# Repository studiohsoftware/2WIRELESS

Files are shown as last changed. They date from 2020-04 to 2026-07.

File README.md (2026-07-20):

# 2WIRELESS
# Wireless Preset Manager

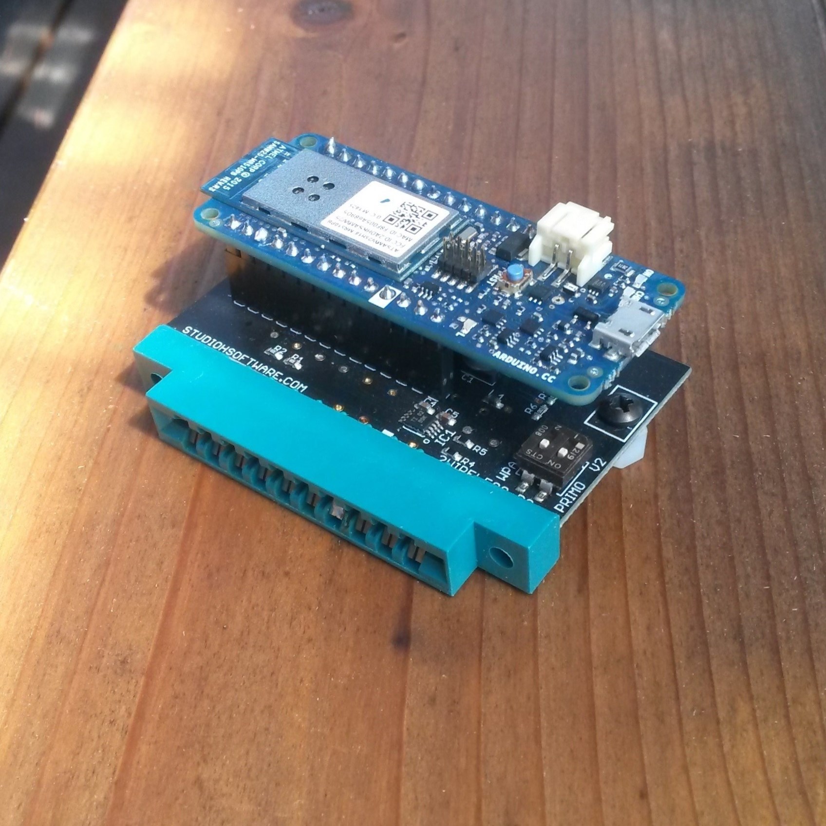
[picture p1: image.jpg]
Studio H Software Wireless Preset Manager


Connect to your Buchla 200e wirelessly and control it using a web page on your phone or computer. 
Change and save presets, upload and download preset data, and even update module firmware.
</br>
</br>
Call URLs to execute MIDI commands. 
</br>
</br>
Run as USB host, and connect a MIDI USB controller directly to your 200e.
Run as USB device, and connect your DAW directly to your 200e. 

## Preset Manager Commands
- ### http://192.168.0.1/remoteenable
Global remote enable.
- ### http://192.168.0.1/remotedisable
Global remote disable.
- ### http://192.168.0.1/savepreset?preset=(1-30)
Save current settings to specified preset.<br/>
Example: http://192.168.0.1/savepreset?preset=1
- ### http://192.168.0.1/recallpreset?preset=(1-30)
Recall specified preset.<br/>
Example: http://192.168.0.1/recallpreset?preset=29
- ### http://192.168.0.1/getpresets?addr=(module addr in hex)
Retrieve all 30 presets from the specified module.<br/>
Example (259A): http://192.168.0.1/getpresets?addr=0x28
- ### http://192.168.0.1/setpresets?addr=(module addr in hex)
Command specified module to read all 30 presets from on-board non-volatile memory.<br/>
Example (259A): http://192.168.0.1/setpresets?addr=(0x28) <br/> </br>
Use writememory to send presets to on-board non-volatile memory first.
Example HTML here https://github.com/studiohsoftware/2WIRELESS/blob/master/Firmware/SetPresets.html <br/>
Example JSON (for 292e) here https://github.com/studiohsoftware/2WIRELESS/blob/master/Firmware/presetData.json <br/>
## MIDI Commands
- ### http://192.168.0.1/midinoteon?chan=(1-16)&note=(0x0-0x7F)&velo=(0x0-0x7F)
Send MIDI note ON message.<br/> 
Example (Channel 9, note G1, half velocity): http://192.168.0.1/midinoteon?chan=9&note=0x1F&velo=0x40
- ### http://192.168.0.1/midinoteoff?chan=(1-16)&note=(0x0-0x7F)&velo=(0x0-0x7F)
Send MIDI note OFF message.<br/>
Example (Channel 16, note F3, max velocity) http://192.168.0.1/midinoteoff?chan=16&note=0x35&velo=0x7F
- ### http://192.168.0.1/midifinetune?chan=(1-16)&tune=(0x00-0x3F)
Send MIDI fine tune message. <br/>
Example (Channel 1, lowest fine tune -49): http://192.168.0.1/midifinetune?chan=1&tune=0x00<br/>
Example (Channel 2, Ft=An): http://192.168.0.1/midifinetune?chan=2&tune=0x32<br/>
Example (Channel 3, highest fine tune +49): http://192.168.0.1/midifinetune?chan=3&tune=0x63<br/>
- ### http://192.168.0.1/midibend?chan=(1-16)&bend_lsb=(0x0-0x7F)&bend_msb=(0x0-0x7F)
Send MIDI bend command.<br/>
Example (Channel 4, lowest bend): http://192.168.0.1/midibend?chan=4&bend_lsb=0x00&bend_msb=0x00<br/>
Example (Channel 5, no bend): http://192.168.0.1/midibend?chan=5&bend_lsb=0x00&bend_msb=0x40<br/>
Example (Channel 6, highest bend): http://192.168.0.1/midibend?chan=6&bend_lsb=0x7F&bend_msb=0x7F
- ### http://192.168.0.1/midiclockstart
Midi clock start.
- ### http://192.168.0.1/midiclockstop
Midi clock stop.
- ### http://192.168.0.1/midiclock
Midi clock. 24 per beat required.
- ### http://192.168.0.1/sendmidibytes?byte1=(0-0xFF)&byte2=(0x0-0x7F)&byte3=(0x0-0x7F)
Send MIDI command as bytes<br/>
Example (Program Change to change preset to 7):</br>
 http://192.168.0.1/sendmidibytes?byte1=C0&byte2=0x07&byte3=0x00<br/>
Example (Control Change to set fine tune to An on channel 5): </br>
http://192.168.0.1/sendmidibytes?byte1=B4&byte2=0x1F&byte3=0x32<br/>
## Configuration Commands
- ### http://192.168.0.1/ssid
Get wireless SSID<br/>
Returns BUCHLA200E by default.
- ### http://192.168.0.1/ssid=(SSID string)
Set wireless SSID<br/>
Example: http://192.168.0.1/ssid=TEST<br/>
Note ssid limited to 32 characters. 
- ### http://192.168.0.1/password
Get wireless WPA password<br/>
Returns BUCHLA200E by default.
- ### http://192.168.0.1/password=(password string)
Set wireless WPA password<br/>
Example: http://192.168.0.1/password=TEST<br/>
Note password must be at least 8 characters and no more than 63 characters.
- ### http://192.168.0.1/usbMode
Get USB Mode. 1=DEVICE, 0=HOST<br/>
- ### http://192.168.0.1/usbMode=(0-1)
Set USB Mode 1=DEVICE, 0=HOST<br/>
Example: Set USB mode to HOST http://192.168.0.1/usbMode=0<br/>
Note restart required for change to take effect.
- ### http://192.168.0.1/presetname?preset=(1-30)
Get preset name<br/>
Example: get name for preset 12 http://192.168.0.1/presetname?preset=12<br/>
- ### http://192.168.0.1/presetname=(preset name string)&preset=(1-30)
Set preset name<br/>
Example: Set name for preset 5 to "Test" http://192.168.0.1/presetname=Test&preset=5<br/>
- ### http://192.168.0.1/velo?chan=(1-16)
Get velocity enable/disable for MIDI channel.<br/>
Example: Get velocity enable value for channel 2 http://192.168.0.1/velo?chan=2<br/>
- ### http://192.168.0.1/velo=(0-1)&chan=(1-16)
Set velocity enable/disable value for MIDI channel.<br/>
Example: Enable velocity on channel 1 http://192.168.0.1/velo=1&chan=1<br/>
- ### http://192.168.0.1/poly?chan=(1-16)
Get poly enable/disable for MIDI channel.<br/>
Example: Get poly enable value for channel 2 http://192.168.0.1/poly?chan=2<br/>
- ### http://192.168.0.1/poly=(0-1)&chan=(1-16)
Set poly enable/disable value for MIDI channel.<br/>
Example: Enable poly on channel 1 http://192.168.0.1/poly=1&chan=1<br/>
- ### http://192.168.0.1/tran?chan=(1-16)
Get transpose value for MIDI channel.<br/>
Example: Get transpose value for channel 3 http://192.168.0.1/tran?chan=3<br/>
- ### http://192.168.0.1/tran=(-49 to 49)&chan=(1-16)
Set transpose value for MIDI channel.<br/>
Example: Set transpose to -30 on channel 1 http://192.168.0.1/tran=-30&chan=1<br/>
- ### http://192.168.0.1/fine?chan=(1-16)
Get fine tune value for MIDI channel.<br/>
Example: Get fine tune value for channel 3 http://192.168.0.1/fine?chan=3<br/>
- ### http://192.168.0.1/fine=(-49 to 49)&chan=(1-16)
Set fine tune value for MIDI channel.<br/>
Example: Set fine tune to An on channel 1 http://192.168.0.1/fine=0&chan=1<br/>
Example: Set fine tune to 30 on channel 5 http://192.168.0.1/fine=30&chan=5<br/>
- ### http://192.168.0.1/mask?chan=(1-16)
Get bus mask for MIDI channel.<br/>
Example: Get mask value for channel 3 http://192.168.0.1/mask?chan=3<br/>
- ### http://192.168.0.1/mask=(0x0-0xF)&chan=(1-16)
Set mask value for MIDI channel.<br/>
Example: Route channel 1 to all four 200e buses http://192.168.0.1/mask=0xF&chan=1<br/>
Example: Route channel 1 to bus A http://192.168.0.1/mask=0x8&chan=1<br/>
Example: Route channel 1 to bus B http://192.168.0.1/mask=0x4&chan=1<br/>
Example: Route channel 1 to bus C http://192.168.0.1/mask=0x2&chan=1<br/>
Example: Route channel 6 to bus D http://192.168.0.1/mask=0x1&chan=6<br/>
## Utility Commands
- ### http://192.168.0.1/readmemory?addr=(0x0-0x03FFFF)&length=0-262143
Read bulk data from on-board non-volatile memory.<br/>
Example (Address 0x1C, return 32 bytes. Note 0x001C, or 0x00001C also acceptable): http://192.168.0.1/readmemory?addr=0x1C&length=32
- ### http://192.168.0.1/writememory?addr=(0x0-0x03FFFF)&data=(hex string)
Write data to on-board non-volatile memory at the specified address.<br/>
Example: (Address 0x1ABCD, five data bytes 0AFF1B0432) http://192.168.0.1/writememory?addr=0x1ABCD&data=0AFF1B0432<br/>
Note all addresses below 0x02C000 are used as scratch space by preset and firmware transfers. 
- ### http://192.168.0.1/writememory
Write bulk data to on-board non-volatile memory.<br/>
Note this is an HTTP POST with a JSON formatted body.<br/> 
Example JSON here https://github.com/studiohsoftware/2WIRELESS/blob/master/Firmware/writeMemoryExample.json<br/>
Notes:
- #### 20k byte JSON file limit.
- #### Addresses are arbitrary locations within 0x0-0x03FFFF.
- #### Data elements can be up to 256 bytes long each (512 characters).
- #### All addresses below 0x02C100 are used as scratch space by preset and firmware transfers. 
## V2 Firmware Support
Old firmware (pre Primo version) also supported. Simply add a "v2" to the URL path. <br/>
Example: http://192.168.0.1/v2/remotedisable<br/>

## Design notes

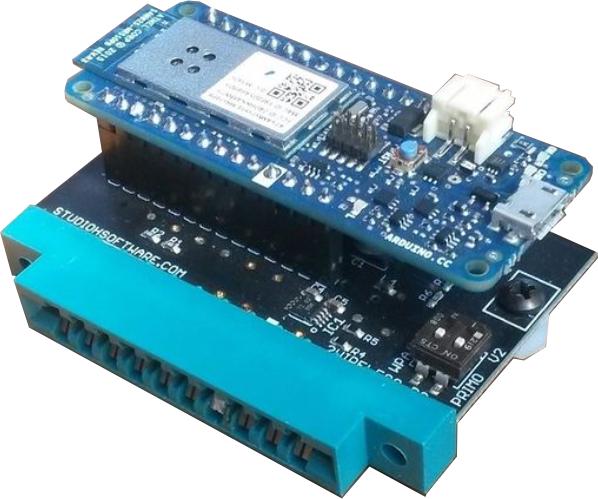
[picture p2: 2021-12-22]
image.png

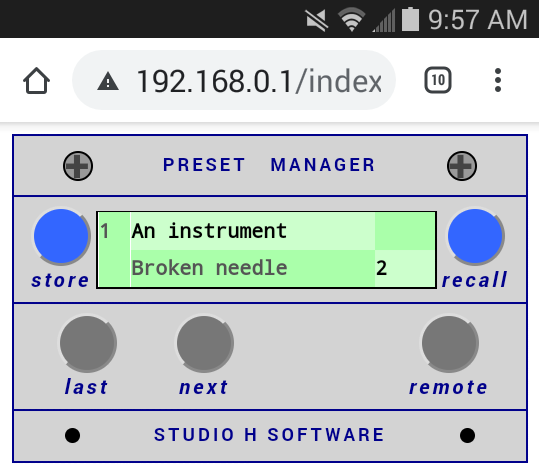
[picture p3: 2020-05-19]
Screenshot.png

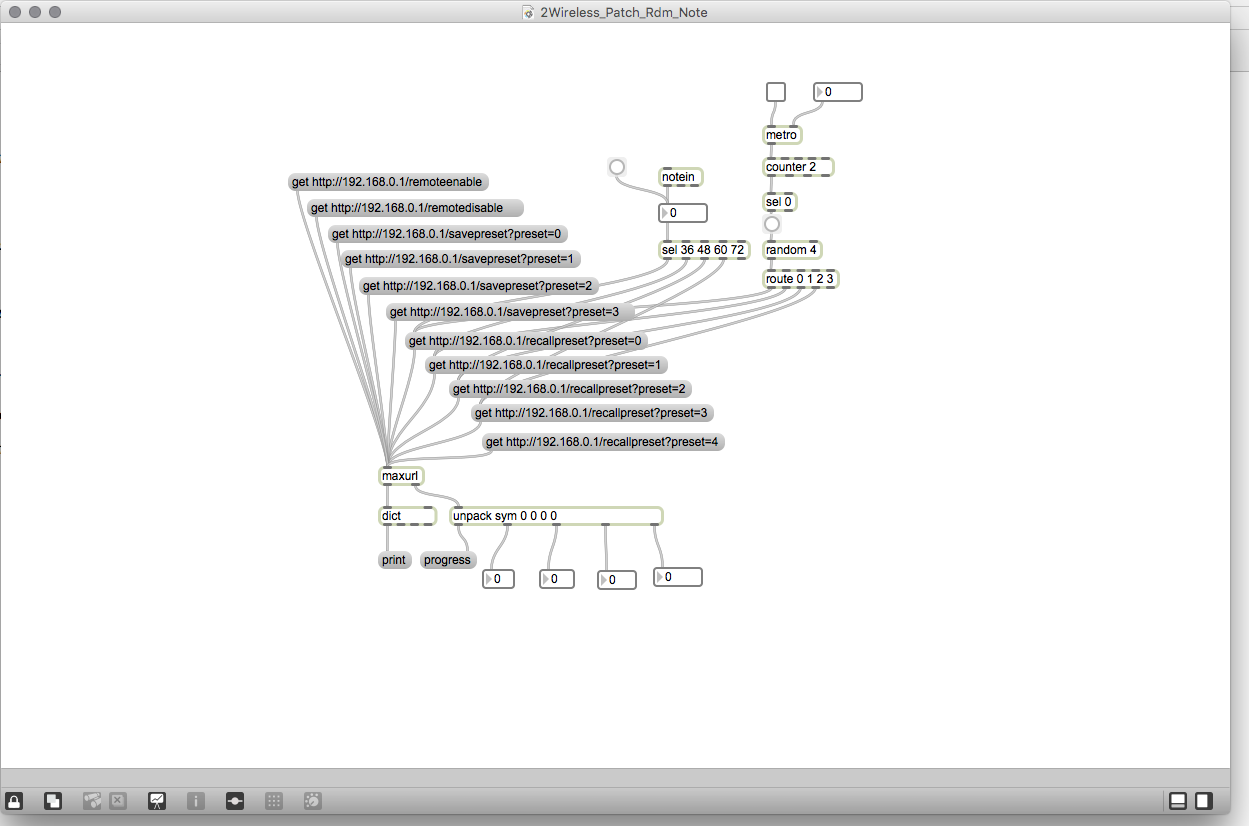
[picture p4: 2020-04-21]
MSPpatch.png

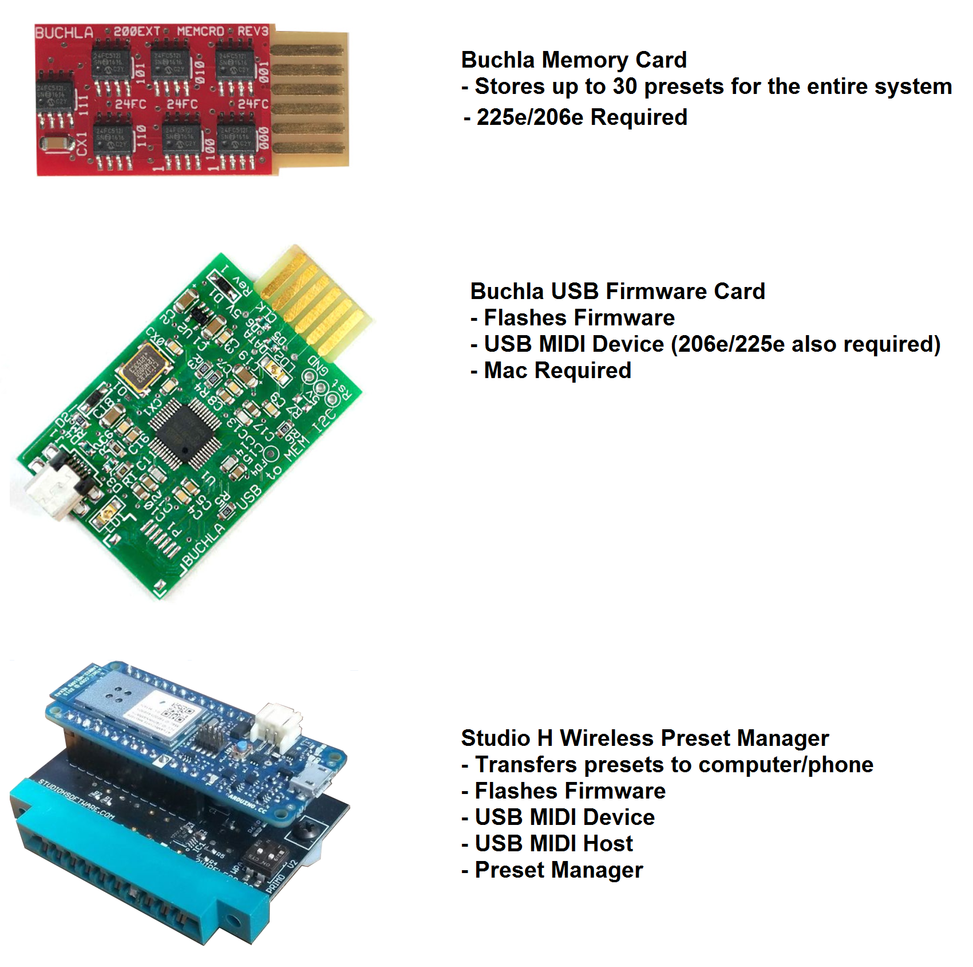
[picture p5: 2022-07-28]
comparison.png

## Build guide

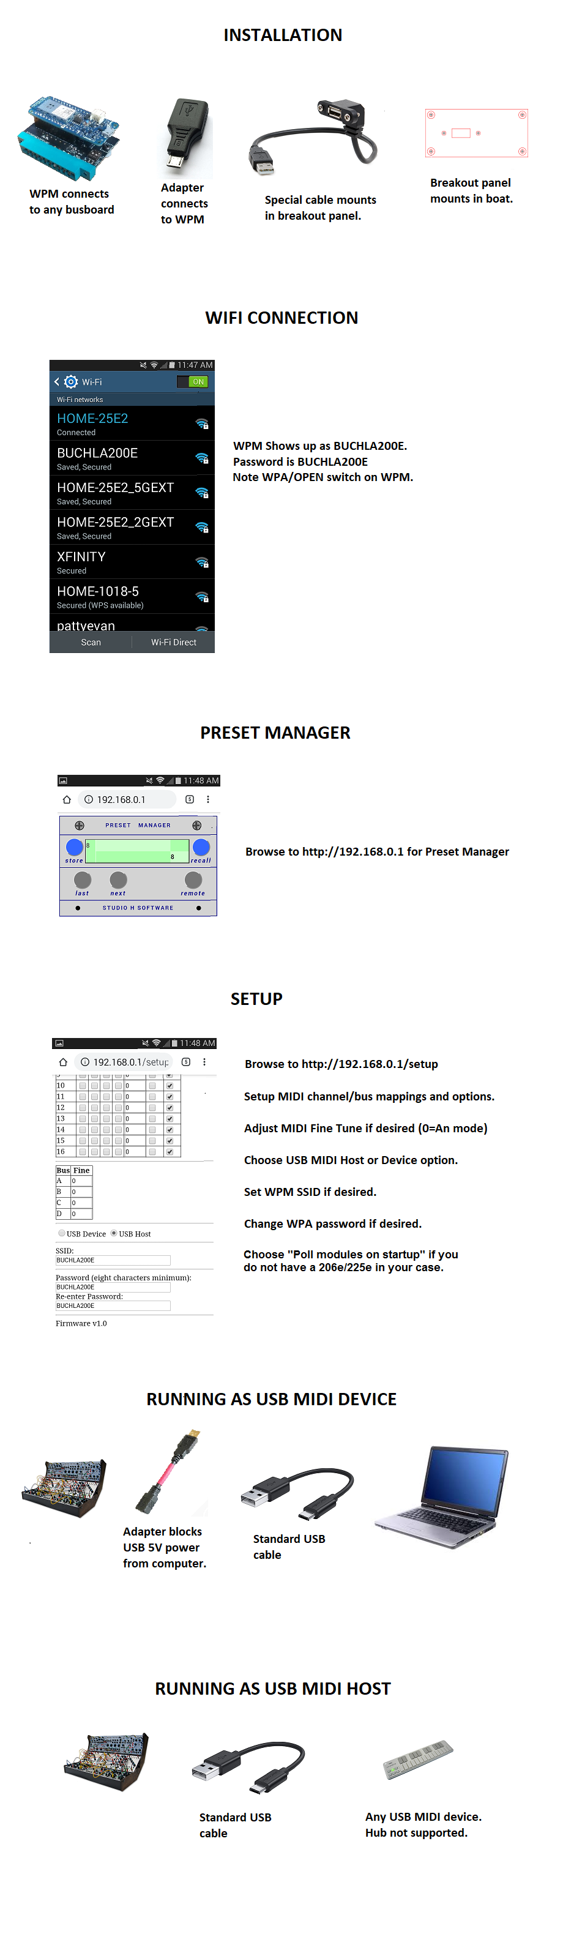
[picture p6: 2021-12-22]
installation.png

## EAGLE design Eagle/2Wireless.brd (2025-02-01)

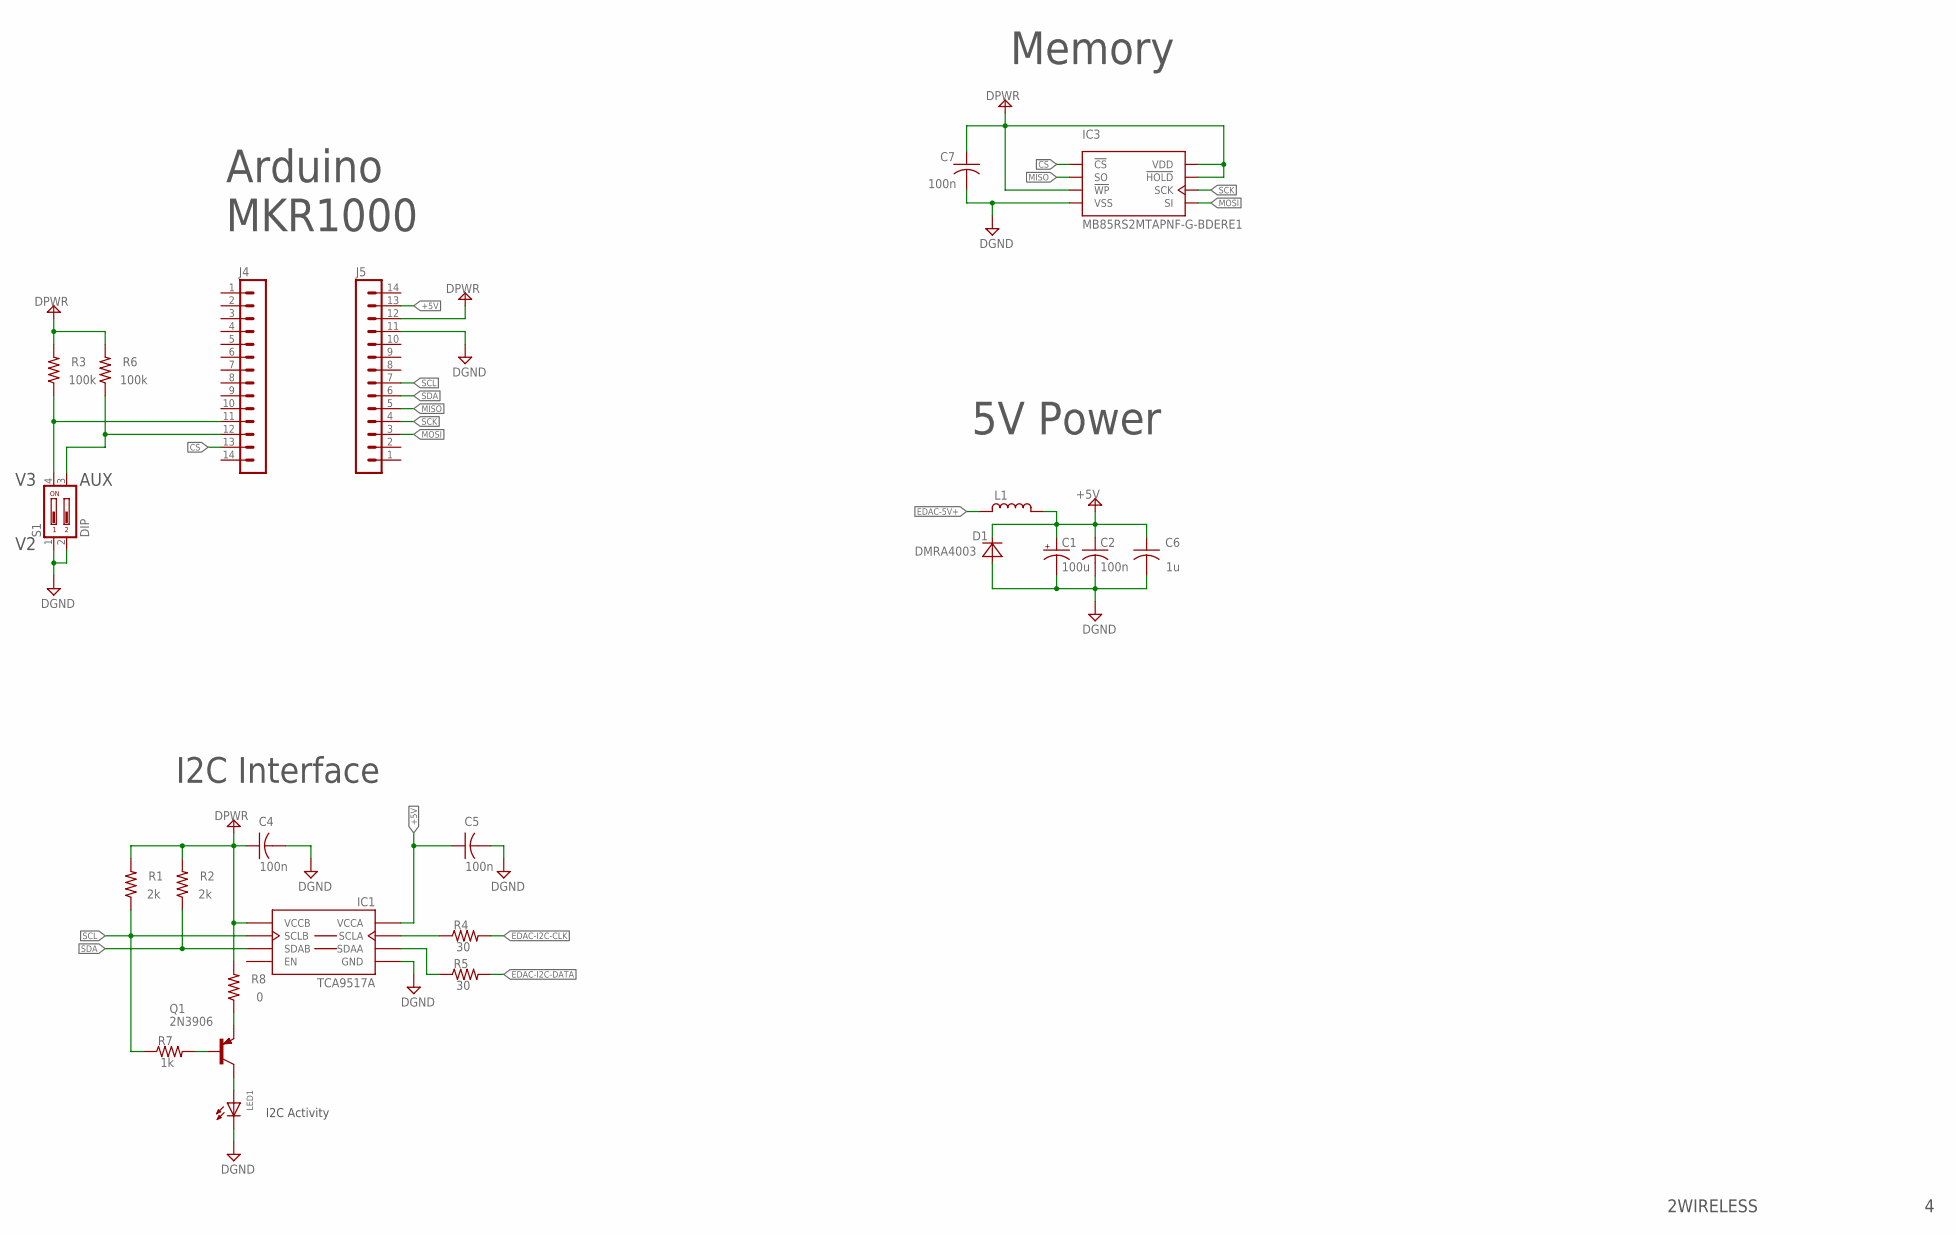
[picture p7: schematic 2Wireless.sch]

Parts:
C1: 100u; PAN-D
C2, C4, C5, C7: 100n; C0603
C6: 1u; C0603
D1: DMRA4003; SMA
IC1: TCA9517A; MSOP8
IC3: MB85RS2MTAPNF-G-BDERE1; SO08
J4, J5: MA14-1
L1: LB; 0603
LED1: LED0805BLUE; CHIPLED_0805
Q1: 2N3906; SOT23
R1, R2: 2k; R0603
R3, R6: 100k; R0603
R4, R5: 30; R0603
R7: 1k; R0603
R8: 0; R0603
S1: DIP; CTS-219-02

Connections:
!CS: IC3.1 (!CS), J4.13
+5V: C1.+, C2.1, C5.1, C6.1, D1.K (C), IC1.1 (VCCA), J5.13, L1.2 (4)
DGND: C1.-, C2.2, C4.2, C5.2, C6.2, C7.2, D1.A, IC1.4 (GND), IC3.4 (VSS), J5.11, LED1.C, S1.1, S1.2
DI-AUX: J4.12, R6.1, S1.3
DI-VERSION: J4.11, R3.1, S1.4
DPWR: C4.1, C7.1, IC1.8 (VCCB), IC3.3 (!WP), IC3.7 (!HOLD), IC3.8 (VDD), J5.12, R1.2, R2.2, R3.2, R6.2, R8.2
EDAC-5V+: L1.1
EDAC-I2C-CLK: R4.2
EDAC-I2C-DATA: R5.2
MISO: IC3.2 (SO), J5.5
MOSI: IC3.5 (SI), J5.3
unnamed: Q1.1 (B), R7.2
unnamed: LED1.A, Q1.2 (C)
unnamed: Q1.3 (E), R8.1
unnamed: IC1.2 (SCLA), R4.1
unnamed: IC1.3 (SDAA), R5.1
SCK: IC3.6 (SCK), J5.4
SCL: IC1.7 (SCLB), J5.7, R1.1, R7.1
SDA: IC1.6 (SDAB), J5.6, R2.1

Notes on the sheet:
2WIRELESS
5V Power
Memory
Arduino MKR1000
I2C Interface
AUX
I2C Activity

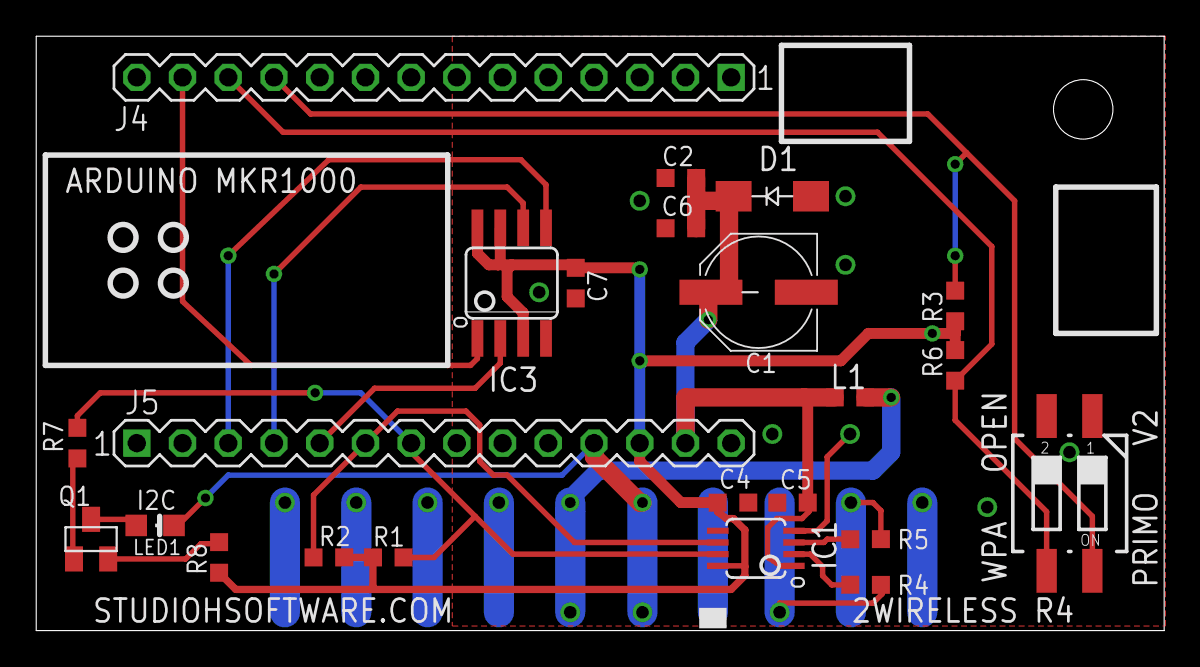
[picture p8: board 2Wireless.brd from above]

Board: 2 copper layers, 62.7 x 33.0 mm, 23 parts (0 on the bottom side), 16 nets.

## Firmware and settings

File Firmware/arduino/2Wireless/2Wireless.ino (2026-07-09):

 /*
 * Pin             |  PORT  | Label
 * ----------------+--------+-------
 *   2       D2    |  PA10  | "V2VERSION_PIN"
 *   3       D3    |  PA11  | "WIFI_OPEN_PIN"
 *   4       D4    |  PB10  | "SPI_CS"
 *   8       D8    |  PA16  | "MOSI"   
 *   9       D9    |  PA17  | "SCK"   
 *   10      D10   |  PA19  | "MISO"  
 *   11      D11   |  PA08  | "SDA"
 *   12      D12   |  PA09  | "SCL"
*/
#include <Wire.h>
#include <WiFi101.h>
#include <SPI.h>
#include <usbh_midi.h>
#include <usbhub.h>
#include <MIDIUSB.h>

//#define DEBUG
//#define DEBUG_HTTP
//#define DEBUG_MIDI //MIDI clock might be too fast for logging. 
//#define DEBUG_PRESETS
//#define DEBUG_USB
//#define DEBUG_I2C
#define CARD_ADDRESS 0x00 //This ends up meaning that our I2C address is 0x50.
#define BUFFER_SIZE 2000 //Ring buffer size for incoming I2C. 
#define FRAM_WREN 0x06 //FRAM WRITE ENABLE COMMAND
#define FRAM_WRITE 0x02 //FRAM WRITE COMMAND
#define FRAM_READ 0x03 //FRAM READ COMMAND
#define SPI_CS 4 //FRAM Chip Select
#define WIFI_OPEN_PIN 3 //Choose WPA or Open
#define V2VERSION_PIN 2 //Choose PRIMO or V2
#define SCL_PIN 12 //Used to check bus before switching to master
#define SDA_PIN 11 //Used to check bus before switching to master
#define SSID_DEFAULT "BUCHLA200E"
#define PASS_DEFAULT "BUCHLA200E"
#define USB_MODE_DEVICE 1
#define USB_MODE_HOST 0
//RESERVED FRAM ADDRESSES 0x02BD19-0x2C128
#define SSID_ADDR 0x02BD19 //32 byte locaton for SSID string
#define PASS_ADDR 0x02BD3A //64 byte location for WPA password string.
#define MIDI_CFG_MASK_ADDR 0x02BE00 //16 bytes for bus masks
#define MIDI_CFG_POLY_ADDR 0x02BE10 //16 bytes for poly 
#define MIDI_CFG_FINE_ADDR 0x02BE20 //16 bytes for fine tune (0x32=An)
#define MIDI_CFG_TRAN_ADDR 0x02BE30 //16 bytes for transpose (0x32=No transpose)
#define MIDI_CFG_VELO_ADDR 0x02BE40 //2 bytes for 16 bools velo y/n.
#define USB_MODE_ADDR 0x02BE42 //1 byte for USB MODE 1=DEVICE 0=HOST
#define POLL_ON_START_ADDR 0x02BE4A //1 byte for POLL ON START 1=POLL 0=NO POLL
#define PROGRAM_CHANGE_ENABLE_ADDR 0x02BE4B //1 byte for enabling preset change on program change. 1=ENABLE 0=DISABLE
#define SEND_MIDI_TO_USB_ADDR 0x02BE4C //1 byte to enable send of MIDI from bus to USB out. 1=ENABLE 0=DISABLE
#define INIT_ADDR 0x02BE43 //six bytes set to DONALD once 1st config is done.
//0x02BE4D - 0x02BE7F Reserved
#define CURRENT_PRESET_ADDR 0x02BE86 //Byte in FRAM memory to track current preset number
#define PRESET_NAME_ADDR 0x02BE87 //Thirty 21 character preset names
#define DISPLAY_MESSAGE_ADDR 0x02C0FE //Two 21 character display message lines
//END RESERVED FRAM ADDRESSES 

//USB Host Convenience Functions
#define Is_uhd_in_received0(p)                    ((USB->HOST.HostPipe[p].PINTFLAG.reg&USB_HOST_PINTFLAG_TRCPT0) == USB_HOST_PINTFLAG_TRCPT0)
#define Is_uhd_in_received1(p)                    ((USB->HOST.HostPipe[p].PINTFLAG.reg&USB_HOST_PINTFLAG_TRCPT1) == USB_HOST_PINTFLAG_TRCPT1)
#define uhd_ack_in_received0(p)                   USB->HOST.HostPipe[p].PINTFLAG.reg = USB_HOST_PINTFLAG_TRCPT0
#define uhd_ack_in_received1(p)                   USB->HOST.HostPipe[p].PINTFLAG.reg = USB_HOST_PINTFLAG_TRCPT1
#define uhd_byte_count0(p)                        usb_pipe_table[p].HostDescBank[0].PCKSIZE.bit.BYTE_COUNT
#define uhd_byte_count1(p)                        usb_pipe_table[p].HostDescBank[1].PCKSIZE.bit.BYTE_COUNT
#define Is_uhd_in_ready0(p)                       ((USB->HOST.HostPipe[p].PSTATUS.reg&USB_HOST_PSTATUS_BK0RDY) == USB_HOST_PSTATUS_BK0RDY)  
#define uhd_ack_in_ready0(p)                       USB->HOST.HostPipe[p].PSTATUSCLR.reg = USB_HOST_PSTATUSCLR_BK0RDY
#define Is_uhd_in_ready1(p)                       ((USB->HOST.HostPipe[p].PSTATUS.reg&USB_HOST_PSTATUS_BK1RDY) == USB_HOST_PSTATUS_BK1RDY)  
#define uhd_ack_in_ready1(p)                       USB->HOST.HostPipe[p].PSTATUSCLR.reg = USB_HOST_PSTATUSCLR_BK1RDY
#define uhd_current_bank(p)                       ((USB->HOST.HostPipe[p].PSTATUS.reg&USB_HOST_PSTATUS_CURBK) == USB_HOST_PSTATUS_CURBK)  

// for debugging
#if defined DEBUG
#define DEBUG_PRINT(str) Serial1.print(str)
#define DEBUG_PRINTLN(str) Serial1.println(str)
#define DEBUG_PRINTHEX(str) Serial1.print(str, HEX)
#define DEBUG_PRINTHEXLN(str) Serial1.println(str, HEX)
#else 
#define DEBUG_PRINT(str)
#define DEBUG_PRINTLN(str)
#define DEBUG_PRINTHEX(str)
#define DEBUG_PRINTHEXLN(str)
#endif

#if defined DEBUG_HTTP
#define DEBUG_HTTP_PRINT(str) Serial1.print(str)
#define DEBUG_HTTP_PRINTLN(str) Serial1.println(str)
#define DEBUG_HTTP_PRINTHEX(str) Serial1.print(str, HEX)
#define DEBUG_HTTP_PRINTHEXLN(str) Serial1.println(str, HEX)
#else
#define DEBUG_HTTP_PRINT(str) 
#define DEBUG_HTTP_PRINTLN(str) 
#define DEBUG_HTTP_PRINTHEX(str) 
#define DEBUG_HTTP_PRINTHEXLN(str) 
#endif

#if defined DEBUG_MIDI
#define DEBUG_MIDI_PRINT(str) Serial1.print(str)
#define DEBUG_MIDI_PRINTLN(str) Serial1.println(str)
#define DEBUG_MIDI_PRINTHEX(str) Serial1.print(str, HEX)
#define DEBUG_MIDI_PRINTHEXLN(str) Serial1.println(str, HEX)
#else
#define DEBUG_MIDI_PRINT(str) 
#define DEBUG_MIDI_PRINTLN(str) 
#define DEBUG_MIDI_PRINTHEX(str) 
#define DEBUG_MIDI_PRINTHEXLN(str) 
#endif

#if defined DEBUG_PRESETS
#define DEBUG_PRESETS_PRINT(str) Serial1.print(str)
#define DEBUG_PRESETS_PRINTLN(str) Serial1.println(str)
#define DEBUG_PRESETS_PRINTHEX(str) Serial1.print(str, HEX)
#define DEBUG_PRESETS_PRINTHEXLN(str) Serial1.println(str, HEX)
#else
#define DEBUG_PRESETS_PRINT(str) 
#define DEBUG_PRESETS_PRINTLN(str) 
#define DEBUG_PRESETS_PRINTHEX(str) 
#define DEBUG_PRESETS_PRINTHEXLN(str) 
#endif

#if defined DEBUG_USB
#define DEBUG_USB_PRINT(str) Serial1.print(str)
#define DEBUG_USB_PRINTLN(str) Serial1.println(str)
#define DEBUG_USB_PRINTHEX(str) Serial1.print(str, HEX)
#define DEBUG_USB_PRINTHEXLN(str) Serial1.println(str, HEX)
#else
#define DEBUG_USB_PRINT(str) 
#define DEBUG_USB_PRINTLN(str) 
#define DEBUG_USB_PRINTHEX(str) 
#define DEBUG_USB_PRINTHEXLN(str) 
#endif

#if defined DEBUG_I2C
#define DEBUG_I2C_PRINT(str) Serial1.print(str)
#define DEBUG_I2C_PRINTLN(str) Serial1.println(str)
#define DEBUG_I2C_PRINTHEX(str) Serial1.print(str, HEX)
#define DEBUG_I2C_PRINTHEXLN(str) Serial1.println(str, HEX)
#else
#define DEBUG_I2C_PRINT(str) 
#define DEBUG_I2C_PRINTLN(str) 
#define DEBUG_I2C_PRINTHEX(str) 
#define DEBUG_I2C_PRINTHEXLN(str) 
#endif

class JsonToken {
    public:
        JsonToken();
        int count;
        int status;
        String data;
};

JsonToken::JsonToken() {
    this->count = 0;
    this->status = 0;
    this->data = "";
}

volatile int read_counter=0; //Used to auto increment read addresses during I2C READ from master.
volatile int write_counter=0; //USed to auto increment write addresses during I2C WRITE from master.
volatile int fram_address=0; //This is global only because it must span OnRequest calls during I2C READ from master. 
volatile bool startup = true; //Used to free 206e when starting up.
volatile bool write_i2c_to_fram = false; //Cache incoming i2c to FRAM.
unsigned long readTime = 0; //used to detect idle to free up 206e at start.
volatile bool i2c_guard = false; //attempt to prevent switch to master while receiving

bool isUsbDevice = true; //Select between USB Device and USB Host
midiEventPacket_t midiMessage; //Convenience structure for carrying MIDI data
RingBuffer usbHostBuffer; //USB Host uses this to decouple interrupt from loop().
USBHost UsbH; //Host object in case we are running as USB Host
USBHub Hub(&UsbH); //Host object
USBH_MIDI  Midi(&UsbH); //Host object
//SAMD21 datasheet pg 836. ADDR location needs to be aligned. 
uint8_t bufBk0[64] __attribute__ ((aligned (4))); //Bank0 used by USB Host
uint8_t bufBk1[64] __attribute__ ((aligned (4))); //Bank1 used by USB Host
bool doPipeConfig = false; //Used to config USB Host pipe after enumeration.
bool usbConnected = false; //Used to throttle activity on USB Host.

int MIDI_EVENT = 0x0800000F; //Leading I2C bytes for 200e MIDI message.
int DISPLAY_EVENT = 0x0A220013; //Leading I2C bytes for 200e module firmware display message.
const uint8_t  MIDI_CLK[4]    = {0x0F, 0xF8, 0, 0}; //used to send 252e clock to USB
const uint8_t  MIDI_CLK_START[4] = {0x0F, 0xFA, 0, 0};
const uint8_t  MIDI_CLK_CONT[4]  = {0x0F, 0xFB, 0, 0};
const uint8_t  MIDI_CLK_STOP[4]  = {0x0F, 0xFC, 0, 0};
uint8_t midiUsbData[4] = {0x00, 0x00, 0x00, 0x00}; //used to decouple incoming I2C from interrupt.
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
void loop() {
  // compare the previous status to the current status
  if (status != WiFi.status()) {
    // it has changed update the variable
    status = WiFi.status();
    if (status == WL_AP_CONNECTED) {
      byte remoteMac[6];
      // a device has connected to the AP
      DEBUG_PRINT("Device connected to AP, MAC address: ");
      WiFi.APClientMacAddress(remoteMac);
      printMacAddress(remoteMac);
      server.begin();
    } else {
      // a device has disconnected from the AP, and we are back in listening mode
      DEBUG_PRINTLN("Device disconnected from AP");
      if (client) client.stop();
    }
  }
  
  client = server.available();   // listen for incoming clients
  //When web page is served, we return to this with no client. 
  //TO DO: If device was disconnected from AP, then it seems AP needs to be reconstructed here.
  if (client) {                             // if you get a client,
    DEBUG_PRINTLN("new client");           // print a message out the serial port
    String currentLine = "";                // make a String to hold incoming data from the client
    String urlString = "";                  // string to hold the request URL
    while (client.connected()) {            // loop while the client's connected
      if (client.available()) {             // if there's bytes to read from the client,
        char c = client.read();             // read a byte, then
        //SerialDebug.write(c);                    // print it out the serial monitor
        if (c == '\n') {                    // if the byte is a newline character
          // if the current line is blank, you got two newline characters in a row.
          // that's the end of the client HTTP request, so send a response:
          if (currentLine.length() == 0) {
            DEBUG_PRINTLN("URL is: " + urlString);
            handleWifiRequest(client, urlString);
            // break out of the while loop:
            break;
          }
          else {      // if you got a newline, then clear currentLine:
            currentLine = "";
          }
        }
        else if (c != '\r') {    // if you got anything else but a carriage return character,
          currentLine += c;      // add it to the end of the currentLine
        }
        if ((currentLine.startsWith("GET") || (currentLine.startsWith("POST"))) && (c == '\r')){
          urlString = currentLine;
        }
      } 
      pollUsbMidi(isUsbDevice);
    }
    // close the connection:
    client.stop();
    delayMicroseconds(1000); //stablizes when load is heavy
    DEBUG_PRINTLN("client disconnected");
    DEBUG_PRINTLN();
  }
  pollUsbMidi(isUsbDevice);
}

void framEnableWrite(){
    SPI.beginTransaction(spiSettings);
    digitalWrite(SPI_CS, LOW); //Set CS low to select chip
    SPI.transfer(FRAM_WREN); // send write enable OPCODE
    digitalWrite(SPI_CS, HIGH); //Set CS high to de-select
    SPI.endTransaction();
}

void framWrite(int addr, uint8_t value){
    //Address on the MB85RS2MTA is 18 bits total, requiring 3 bytes. 
    uint8_t addr_byte_upper = (0x3F0000 & addr) >>16;
    uint8_t addr_byte_middle = (0x00FF00 & addr) >>8;
    uint8_t addr_byte_lower = (0x0000FF & addr);
    framEnableWrite();
    SPI.beginTransaction(spiSettings);
    digitalWrite(SPI_CS, LOW); //Set CS low to select chip
    SPI.transfer(FRAM_WRITE); // send write enable OPCODE
    SPI.transfer(addr_byte_upper); // send address upper byte
    SPI.transfer(addr_byte_middle); // send address middle byte
    SPI.transfer(addr_byte_lower); // send address lower byte
    SPI.transfer(value); // send value
    digitalWrite(SPI_CS, HIGH); //Set CS high to de-select
    SPI.endTransaction();
}

void framWriteHexString(int addr, String value){
    //Address on the MB85RS2MTA is 18 bits total, requiring 3 bytes. 
    uint8_t addr_byte_upper = (0x3F0000 & addr) >>16;
    uint8_t addr_byte_middle = (0x00FF00 & addr) >>8;
    uint8_t addr_byte_lower = (0x0000FF & addr);
    framEnableWrite();
    SPI.beginTransaction(spiSettings);
    digitalWrite(SPI_CS, LOW); //Set CS low to select chip
    SPI.transfer(FRAM_WRITE); // send write enable OPCODE
    SPI.transfer(addr_byte_upper); // send address upper byte
    SPI.transfer(addr_byte_middle); // send address middle byte
    SPI.transfer(addr_byte_lower); // send address lower byte
    String remainder = value;
    while (remainder.length() >= 2){
        uint8_t data = (int)strtol(remainder.substring(0,2).c_str(), nullptr, 16); 
        SPI.transfer(data); // send value
        remainder = remainder.substring(2,remainder.length());
    }
    digitalWrite(SPI_CS, HIGH); //Set CS high to de-select
    SPI.endTransaction();
}

uint8_t framRead(int addr){
    uint8_t result = 0x00;
    //Address on the MB85RS2MTA is 18 bits total, requiring 3 bytes. 
    uint8_t addr_byte_upper = (0x3F0000 & addr) >>16;
    uint8_t addr_byte_middle = (0x00FF00 & addr) >>8;
    uint8_t addr_byte_lower = (0x0000FF & addr);
    SPI.beginTransaction(spiSettings);
    digitalWrite(SPI_CS, LOW); //Set CS low to select chip
    SPI.transfer(FRAM_READ); // send write enable OPCODE
    SPI.transfer(addr_byte_upper); // send address upper byte
    SPI.transfer(addr_byte_middle); // send address middle byte
    SPI.transfer(addr_byte_lower); // send address lower byte
    result = SPI.transfer(0); // read byte
    digitalWrite(SPI_CS, HIGH); //Set CS high to de-select
    SPI.endTransaction();
    return result;
}

String getFramString(int addr, int len) {
  String result = "";
  int offset = 0;
  int tmp = framRead(addr + offset); 
  while ((tmp > 31) && (tmp < 0x7F) && (offset < len)) {
    result = result + char(tmp);
    offset++;
    tmp = framRead(addr + offset);
  }
  return result;
}

void setFramString(String value, int addr){
  for (int i=0;i<value.length();i++){
    char c = value.charAt(i);
    framWrite(addr + i,c);
  } 
}

void initializeFram() {
  //Check if already initialized.
  if (getFramString(INIT_ADDR,6) == "DONALD") {
    //Read values from FRAM
    for (int i=0;i<16;i++){
      mask[i] = framRead(MIDI_CFG_MASK_ADDR + i);
      poly[i] = framRead(MIDI_CFG_POLY_ADDR + i);
      tran[i] = framRead(MIDI_CFG_TRAN_ADDR + i);
      velo[i] = getVelo(i); //array of bool
    }  
    for (int i=0;i<4;i++){
      fine[i] = framRead(MIDI_CFG_FINE_ADDR + i);
    }
  } else {
    //Write default values to fram.
    uint16_t velocity = 0x0;
    for (int i=0;i<16;i++){
      framWrite(MIDI_CFG_MASK_ADDR + i,mask[i]);
      framWrite(MIDI_CFG_POLY_ADDR + i,poly[i]);
      framWrite(MIDI_CFG_TRAN_ADDR + i,tran[i]);
      setVelo(i,velo[i]);
    }
    for (int i=0;i<4;i++){
      framWrite(MIDI_CFG_FINE_ADDR + i,fine[i]);
    }
    setUsbMode(USB_MODE_DEVICE); 
    setPollOnStart(0);
    setProgramChangeEnable(0);
    setSendMidiToUsb(0);
    setCurrentPreset(1); //just to have something in there.
    //Mark as initialized for next time.
    setFramString("DONALD", INIT_ADDR);
  } 
}

void setMask(uint8_t chan, uint8_t val){
  //Channel is 0-15
  if (mask[chan] != val){
    mask[chan] = val;
    framWrite(MIDI_CFG_MASK_ADDR + chan,mask[chan]); 
  }
}

void setPoly(uint8_t chan, uint8_t val){
  //Channel is 0-15
  if (poly[chan] != val){
    poly[chan] = val;
    framWrite(MIDI_CFG_POLY_ADDR + chan,poly[chan]); 
  }
  if (val) {
    polyAvail[chan]=0xF; //init to all buses available
    polyNotes[chan] = 0xFFFFFFFF;
  }
}

void setFine(uint8_t bus, uint8_t val){
  //Bus is 0-3
  //Always send so that setup Submit after boot works
  fine[bus] = val;
  framWrite(MIDI_CFG_FINE_ADDR + bus,fine[bus]); 
  sendMidiFineTune(busMask[bus],fine[bus]);
}

void setTran(uint8_t chan, uint8_t val){
  //Channel is 0-15
  if (tran[chan] != val) {
    tran[chan] = val;
    framWrite(MIDI_CFG_TRAN_ADDR + chan,tran[chan]);
  }
}

bool getVelo(uint8_t chan){
  uint16_t velocity = framRead(MIDI_CFG_VELO_ADDR) & 0x00FF;
  velocity = velocity | (framRead(MIDI_CFG_VELO_ADDR + 1) << 8); 
  return velocity & (1<<chan);
}

void setVelo(uint8_t chan, bool val) {
  velo[chan] = val;
  uint16_t velocity = framRead(MIDI_CFG_VELO_ADDR) & 0x00FF;
  velocity = velocity | (framRead(MIDI_CFG_VELO_ADDR + 1) << 8);
  uint16_t shifter = 1 << chan;
  velocity = velocity & ~shifter; //clear the current bit.
  velocity = velocity | (val << chan); //Save the desired bit.
  framWrite(MIDI_CFG_VELO_ADDR,velocity & 0x00FF);
  framWrite(MIDI_CFG_VELO_ADDR + 1,(velocity & 0xFF00)>>8);
}

bool getUsbMode() {
  return (framRead(USB_MODE_ADDR) > 0);
}

void setUsbMode(bool mode){
  if (mode == USB_MODE_DEVICE) {
    isUsbDevice = true;
  } else {
    isUsbDevice = false;
  }
  framWrite(USB_MODE_ADDR,mode);
}

bool getPollOnStart() {
  return (framRead(POLL_ON_START_ADDR) > 0);
}
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

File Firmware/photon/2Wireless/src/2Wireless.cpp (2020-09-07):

// #pragma SPARK_NO_PREPROCESSOR


#include "Particle.h"
#include "Arduino.h"
#include "softap_http.h"
#include "Wire.h"
#include "SPI.h"


SYSTEM_THREAD(ENABLED);
SYSTEM_MODE(MANUAL); //Found in softap.cpp example. 

#define CARD_ADDRESS 0x00
#define BUFFER_SIZE 4800
#define FRAM_WREN 0x06 //FRAM WRITE ENABLE COMMAND
#define FRAM_WRITE 0x02 //FRAM WRITE COMMAND
#define FRAM_READ 0x03 //FRAM READ COMMAND

class JsonToken {
    public:
        JsonToken();
        int count;
        int status;
        String data;
};

JsonToken::JsonToken() {
    this->count = 0;
    this->status = 0;
    this->data = "";
}


class RingBuffer {
    private:
        volatile uint8_t buffer[BUFFER_SIZE];
        volatile uint32_t head;
        volatile uint32_t tail;  
    public:
        RingBuffer();
        int bytesFree(void);
        int bytesQueued(void);
        uint8_t read(void);
        void write(uint8_t byte);
        void flush();
};

RingBuffer::RingBuffer() {
    this->head = 0;
    this->tail = 0;
    this->buffer[0] = 0;
}

int RingBuffer::bytesQueued(void) {
     int result = 0;
    result = (unsigned int)(BUFFER_SIZE + this->head - this->tail) % BUFFER_SIZE;
    return result;
}

int RingBuffer::bytesFree(void) {
    return BUFFER_SIZE - this->bytesQueued();
}

uint8_t RingBuffer::read(void){
    uint8_t result = 0x00;
    if (this->bytesQueued() > 0){
        result = this->buffer[this->tail];
        this->tail = (uint32_t)(this->tail+1) % BUFFER_SIZE;
    }
    return result; //Note byte returned, so always call bytesQueued() first to check.
}
 
void RingBuffer::write(uint8_t byte){
    if (this->bytesFree()>0) {
        this->buffer[this->head] = byte;
        this->head = (uint32_t)(this->head + 1) % BUFFER_SIZE;
    }
}

void RingBuffer::flush() {
    this->tail = this->head;
}

RingBuffer ringBuffer = RingBuffer(); //Used to buffer data between HTTP and I2C.
volatile int read_counter; //Used to auto increment read addresses during I2C READ from master.
volatile int fram_address=0; //This is global only because it must span OnRequest calls during I2C READ from master. 
volatile bool startup = true; //Used to free 206e when starting up.
unsigned long readTime = 0; //used to detect idle to free up 206e at start.
bool v2version=false; //used to support pre PRIMO firmware.

void framEnableWrite(){
    digitalWrite(A2, LOW); //Set CS low to select chip
    SPI.transfer(FRAM_WREN); // send write enable OPCODE
    digitalWrite(A2, HIGH); //Set CS high to de-select
}

void framWrite(int addr, uint8_t value){
    framEnableWrite();
    //Address on the MB85RS2MTA is 18 bits total, requiring 3 bytes. 
    uint8_t addr_byte_upper = (0x3F0000 & addr) >>16;
    uint8_t addr_byte_middle = (0x00FF00 & addr) >>8;
    uint8_t addr_byte_lower = (0x0000FF & addr);
    digitalWrite(A2, LOW); //Set CS low to select chip
    SPI.transfer(FRAM_WRITE); // send write enable OPCODE
    SPI.transfer(addr_byte_upper); // send address upper byte
    SPI.transfer(addr_byte_middle); // send address middle byte
    SPI.transfer(addr_byte_lower); // send address lower byte
    SPI.transfer(value); // send value
    digitalWrite(A2, HIGH); //Set CS high to de-select
}

void framWriteHexString(int addr, String value){
    framEnableWrite();
    //Address on the MB85RS2MTA is 18 bits total, requiring 3 bytes. 
    uint8_t addr_byte_upper = (0x3F0000 & addr) >>16;
    uint8_t addr_byte_middle = (0x00FF00 & addr) >>8;
    uint8_t addr_byte_lower = (0x0000FF & addr);
    digitalWrite(A2, LOW); //Set CS low to select chip
    SPI.transfer(FRAM_WRITE); // send write enable OPCODE
    SPI.transfer(addr_byte_upper); // send address upper byte
    SPI.transfer(addr_byte_middle); // send address middle byte
    SPI.transfer(addr_byte_lower); // send address lower byte
    String remainder = value;
    while (remainder.length() >= 2){
        uint8_t data = (int)strtol(remainder.substring(0,2).c_str(), nullptr, 16); 
        SPI.transfer(data); // send value
        remainder = remainder.substring(2,remainder.length());
    }
    digitalWrite(A2, HIGH); //Set CS high to de-select
}

uint8_t framRead(int addr){
    uint8_t result = 0;
    //Address on the MB85RS2MTA is 18 bits total, requiring 3 bytes. 
    uint8_t addr_byte_upper = (0x3F0000 & addr) >>16;
    uint8_t addr_byte_middle = (0x00FF00 & addr) >>8;
    uint8_t addr_byte_lower = (0x0000FF & addr);
    digitalWrite(A2, LOW); //Set CS low to select chip
    SPI.transfer(FRAM_READ); // send write enable OPCODE
    SPI.transfer(addr_byte_upper); // send address upper byte
    SPI.transfer(addr_byte_middle); // send address middle byte
    SPI.transfer(addr_byte_lower); // send address lower byte
    result = SPI.transfer(0); // read byte
    digitalWrite(A2, HIGH); //Set CS high to de-select
    return result;
}

void receiveEvent(int howMany) {
    while (Wire.available() > 0) {   
        //Just assume room in buffer to avoid blocking.
        ringBuffer.write(Wire.read()); //Save into ring buffer to support I2C WRITE from master.
    }
}
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

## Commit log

2019-08-12 Original version.
    Device will appear as a wireless access point. Connect and navigate to http://192.168.0.1.
    Note calls to System.set SYSTEM_CONFIG_SOFTAP_DISABLE_BROADCAST enable and disable the SSID broadcast for security. These options must be commented out unless Particle Workbench is used to local comp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
    [2Wireless.brd, 2Wireless.sch]
2019-08-18 Add remote enable/disable URLs.
    Investigate fetching preset data from 291e, but I don't think I can do mulitple master without modifying the core. Hoping to avoid that. Note also that Photon has only one I2C device.
    [2Wireless.ino]
2019-08-18 Preset data received from 291e using getpresetdata.
    However, I chop it off after 10 bytes so it freezes the bus when switching back to master because the 291e is still talking. Need to actually read bytes in and look for terminating byte sequence from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
2019-08-19 REST call /getpresets?addr=<hex addr> seems to be working.
    Note that timer was used (unfortunately) to determine when the received byte stream is done. Modules send end backup message, but it is general call, which appears to be yet unsupported for Wire libr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
2019-08-19 Switch to slave mode to prevent conflict with modules running in master mode.
    Streamline getpresets response to eliminate large response string.
    Current approach of data[8000] will need to be changed. 291e sends about 4k, but 251e will exceed 8k. Probably need some kind of volatile ring buffer so receiveEvent can write and getpresets can read. Might be tricky avoiding buffer underrun and early exit.
    [2Wireless.ino]
2019-08-22 Added ring buffer and new commands recallpreset and savepreset.
    Note that guarding the ring buffer access in receiveEvent() did not work. Any blocking there interfered with I2C processing and hung the Photon. I tried WITH_LOCK, TRY_LOCK, and various mutex strategies.
    [2Wireless.ino]
2019-08-23 Add midi note on command. Other midi commands staged for URL handlers.
2019-08-26 Remove check for unused bytes before writing to ring buffer in receiveEvent. Hopefully this eliminates occasional I2C hang during getpresets.
2019-09-19 Added URL writefirmware, added draft html POST example WriteFirmware.html, and test data test.hex.
    Currently just echoes the data opened in test.hex back to the browser.
2019-11-16 Change FRAM to 256k.
    [2Wireless.brd, 2Wireless.sch]
2020-04-21 Get presets now working.
    Cleaned up getpresets, and added optional length parameter to place carriage returns in result for teasing out patterns in the preset data.
    Added bin files so that everything can be flashed via command line in DFU mode.
    Modified readmemory and writememory for new 2M FRAM chip. 256K bytes now available. Note this breaks three prototype units already in the field which are running on 32K byte version.
2020-04-25 Check in to save work on writing presets.
    JSON parser working on example 292e preset file.
    Discovered maximum POST side of 20400 to the Photon.
    Also some work on I2C reads from master. Untested.
2020-04-28 Fix JSON formatting errors. Add GetPresets.html.
    [2Wireless.ino]
2020-05-01 Checking in to save html files.
    SetPresets not working due to hardware limitations.
    [2Wireless.ino]
2020-05-02 Added two 24FC512. Photon unreliable as I2C slave.
    [2Wireless.brd, 2Wireless.sch]
2020-05-02 Add two more 24FC512.
    [2Wireless.brd, 2Wireless.sch]
2020-05-04 Modify Photon core to call OnRequest every byte.
    GetPresets.html fixed for 291e.
    2Wireless.ino checkpoint. Still in progress.
    [2Wireless.ino, i2c_hal.c, i2c_hal.h]
2020-05-04 Added fix to rxBuffer within i2c_hal.c.
    Removed bool parameter from OnRequest.onRequest
    Tested framRead within OnRequest.
    [2Wireless.ino, i2c_hal.c, i2c_hal.h]
2020-05-05 Fixed 251e in GetPresets.html.
    [2Wireless.ino]
2020-05-11 Fixed up WriteFirmware.html based on 251e.
    Modified OnRequest to handle 1-3 address bytes.
    [2Wireless.ino]
2020-05-13 Remove 24FC512 chips. Not needed.
    [2Wireless.brd, 2Wireless.sch]
2020-05-17 Improve buttons on PresetManager.html
2020-05-23 Send remote disable on startup to unlock 206e
    Also set on board D7 LED to light up during I2C
    READ operations so that you can tell a firmware
    load is in progress.
2020-06-17 Add Primo/V2 version switch.
    [2Wireless.brd, 2Wireless.sch]
2020-07-01 Add primo/v2 hardware switch.
    Hide version radio buttons.
2020-07-18 Add RS232 Connector for future use.
    [2Wireless.brd, 2Wireless.sch]
2020-07-22 Switch layout from Photon to Arduino MKR1000.
    [2Wireless.brd, 2Wireless.sch]
2020-08-09 Add I2C pullups to MKR1000 layout.
    [2Wireless.brd, 2Wireless.sch]
2020-09-07 Create separate photon and arduino areas.
2020-09-08 Fixed bug in generate_204 case.
    [2Wireless.ino]
2020-09-11 I2C not working. Check in to save work.
    [2Wireless.ino]
2020-09-14 Change power source on TCA9517A.
    [2Wireless.brd, 2Wireless.sch]
2020-09-16 Add labels to aux switch for open/wpa.
    [2Wireless.brd]
2020-09-26 Remove triggerRemoteEnable approach. I2C broken.
    [2Wireless.ino]
2020-09-29 Add 10 uS delay before switching I2C modes.
2020-09-29 SPI now working.
2020-10-01 WIFI and VERSION switches MKR1000.
    Also have GetPresets.html working, but buffer overrun on 251e.
2020-10-21 Lower max transfer size in WriteFirmware.html.
    Photon running out of memory.
    Also, MKR1000 firmware update not working.
    [2Wireless.ino]
2020-12-13 Add MIDIUSB device handler for testing.
2020-12-16 Add USB Host and Device for testing.
2020-12-17 Current preset now tracked in firmware.
    Changing presets by program change,
    or by recallpreset URL both track current
    preset now.
2020-12-19 Add currentpreset URL.
2020-12-20 Add device description.
2020-12-21 Add URL to get/set usbMode (HOST/DEVICE).
2020-12-29 Add more timeout to switch to slave.
    Also bug on poly bus D fixed.
    [2Wireless.ino]
2020-12-31 Add MIDI CC messages for preset manager functions.
    Also handle undefined case in preset names.
2021-01-12 Add hole for standoff.
    [2Wireless.brd]
2021-01-23 Increase hole size for standoff.
    [2Wireless.brd]
2021-02-02 Add VID/PID and display version on setup page.
2021-04-18 Fix USB device enum problem on cable reconnect.
    [2Wireless.ino]
2021-04-20 In progress - SEND MIDI TO USB.
    Working for USB Device. Need to add checkbox to setup page.
    Potential problem for USB host. SQ-1 presents MIDIOUT2 for clocks
    from host. Should WPM offer a choice of destinations, or only
    support this in USB Device mode?
    Also added stub for ENABLE MIDI PROGRAM CHANGE to allow
    user to turn off preset change when MIDI PROGRAM CHANGE
    is received.
    [2Wireless.ino]
2021-05-10 Neuter 252e clock publishing.
    Test caused lockup. 2nd USB pipe probably reqd.
    Note WPM hanging after WriteFirmware, and LED not flashing.
    Also WriteFirmware often fails, requiring many attempts.
    [2Wireless.ino]
2021-10-27 Add option to publish 252e MIDI clock over USB.
    Supported in USB Device mode only.
2022-01-25 Change from readName to readNames in PresetManager
    Fixes hang at PresetManager page refresh.
    [2Wireless.ino]
2022-01-25 Fix %20 problem in preset names.
    [2Wireless.ino]
2024-02-07 Fix border around preset manager display.
    [2Wireless.ino]
2024-06-02 Update 2Wireless.ino
    Added null pointer fix
    [2Wireless.ino]
2024-06-07 Update 2Wireless.ino to v1.9
    Wifi reconnect fixed
    [2Wireless.ino]
2025-02-01 Add blue LED for I2C activity
    [2Wireless.brd, 2Wireless.sch]
2025-06-30 Add firmware display, favicon, improved bus stability.
    [2Wireless.ino]
2025-07-01 Restore check for sendMidiToUsb in I2C listener.
2026-03-02 Add offline favicon.ico for fun.
    Offer favicon.ico for offline web pages. Just make sure the ico file is in the same directory as the html files on your computer/phone.
    Also adjusted a couple of module formats in GetPresets,html because they seemed to be out of sync.
2026-03-07 Add firmware display button.
2026-07-09 Increase delay for stop condition when switching to I2C slave.
